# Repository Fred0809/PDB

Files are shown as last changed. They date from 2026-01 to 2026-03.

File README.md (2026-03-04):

# PDB
The project uses XT60 conenctor for battery input and screw terminals for ESCs output. The board idea is to have fuse, current measurement, and buck converter to 5V. Curent measuremnt from INA amp is sent to FCU, mounted above, with JST-XH conenctor together with 5V, VBAT voltage measurement, and GND.

<p align="center">
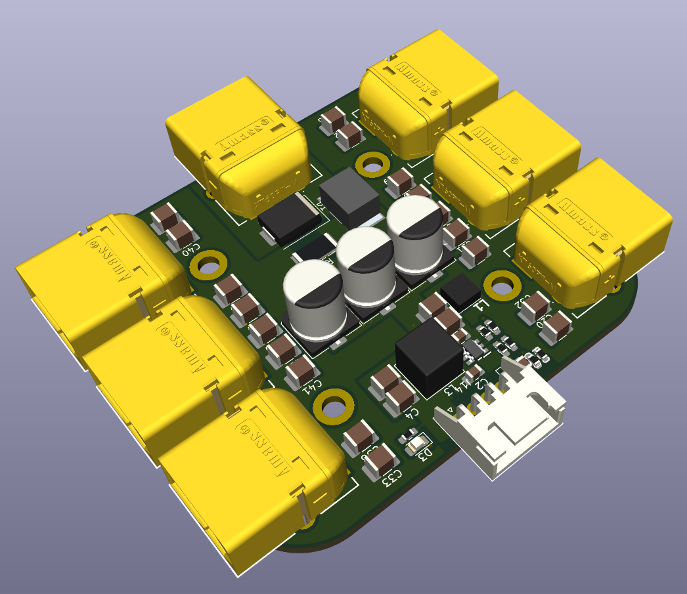
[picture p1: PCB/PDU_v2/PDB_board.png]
  
</p>

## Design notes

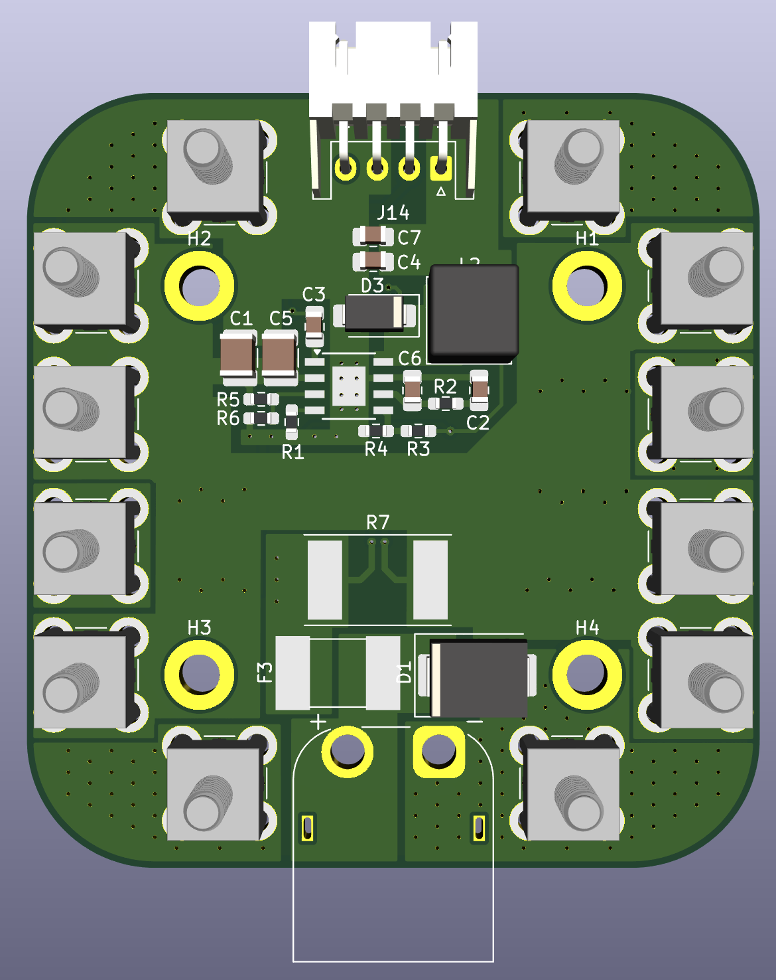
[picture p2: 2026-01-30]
PCB/PDU_v1_pcb_view.png

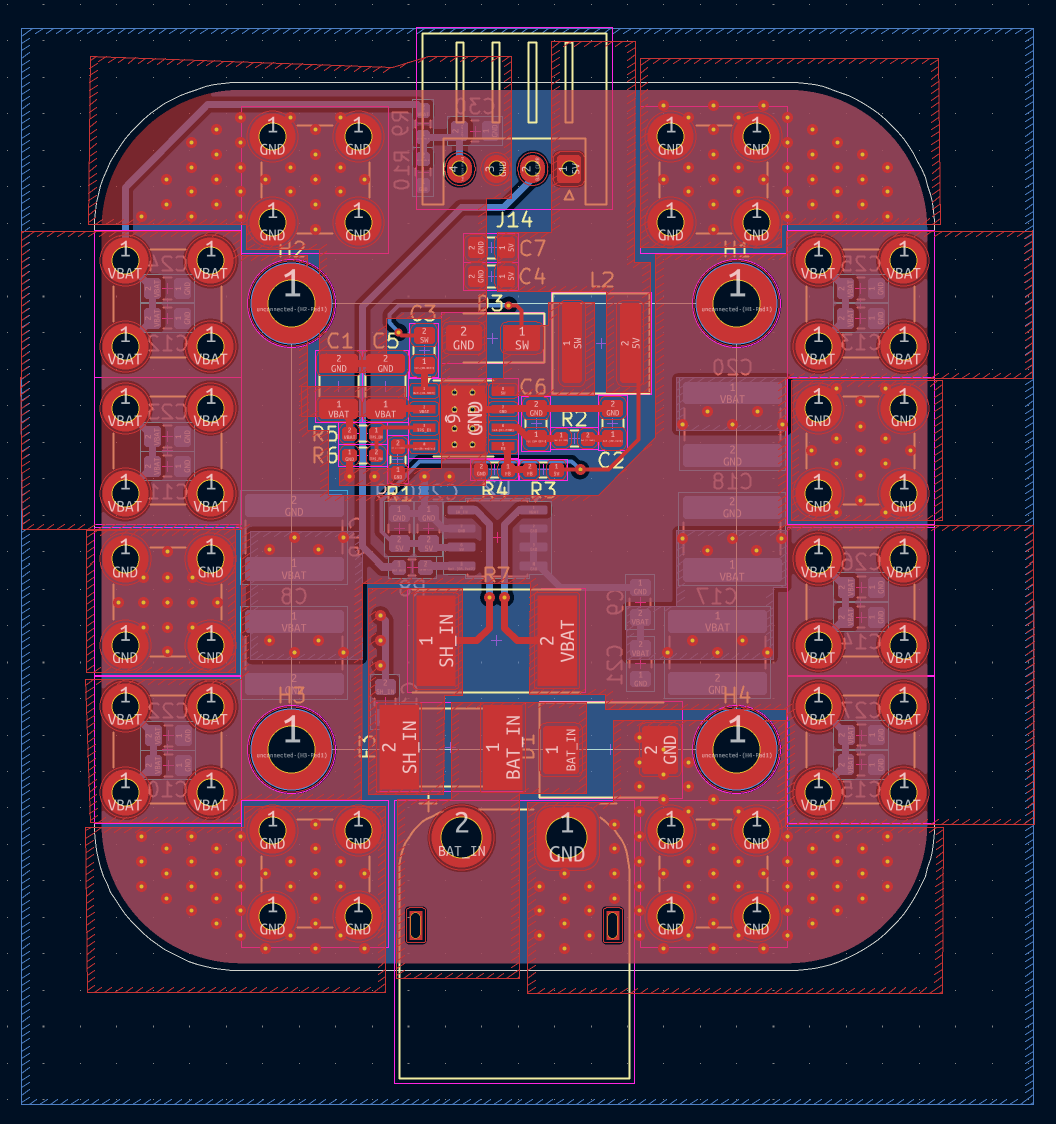
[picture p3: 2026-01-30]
PCB/PDU_v1_pcb.png

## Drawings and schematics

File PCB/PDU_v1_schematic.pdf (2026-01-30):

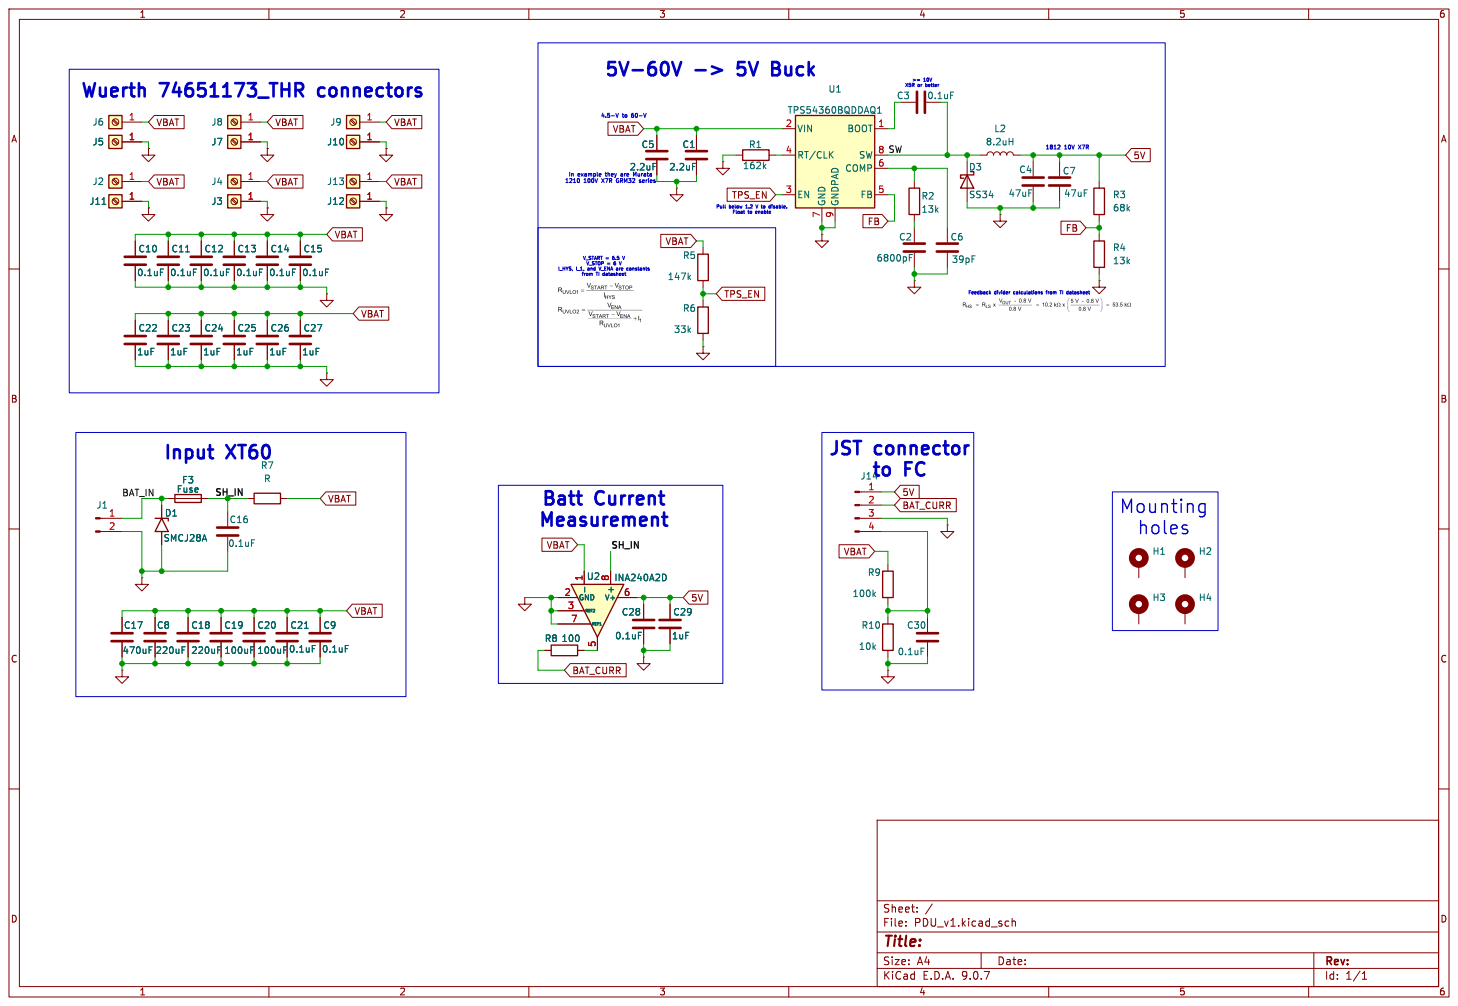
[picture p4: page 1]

9 BOOT 1 SW 8 COMP 6 FB 5 U1 TPS54360BQDDAQ1 VBAT VBAT VBAT VBAT VBAT VBAT VBAT VBAT VBAT VBAT VBAT

Id: 1/1 Title: File: PDU_v1.kicad_sch Sheet: /

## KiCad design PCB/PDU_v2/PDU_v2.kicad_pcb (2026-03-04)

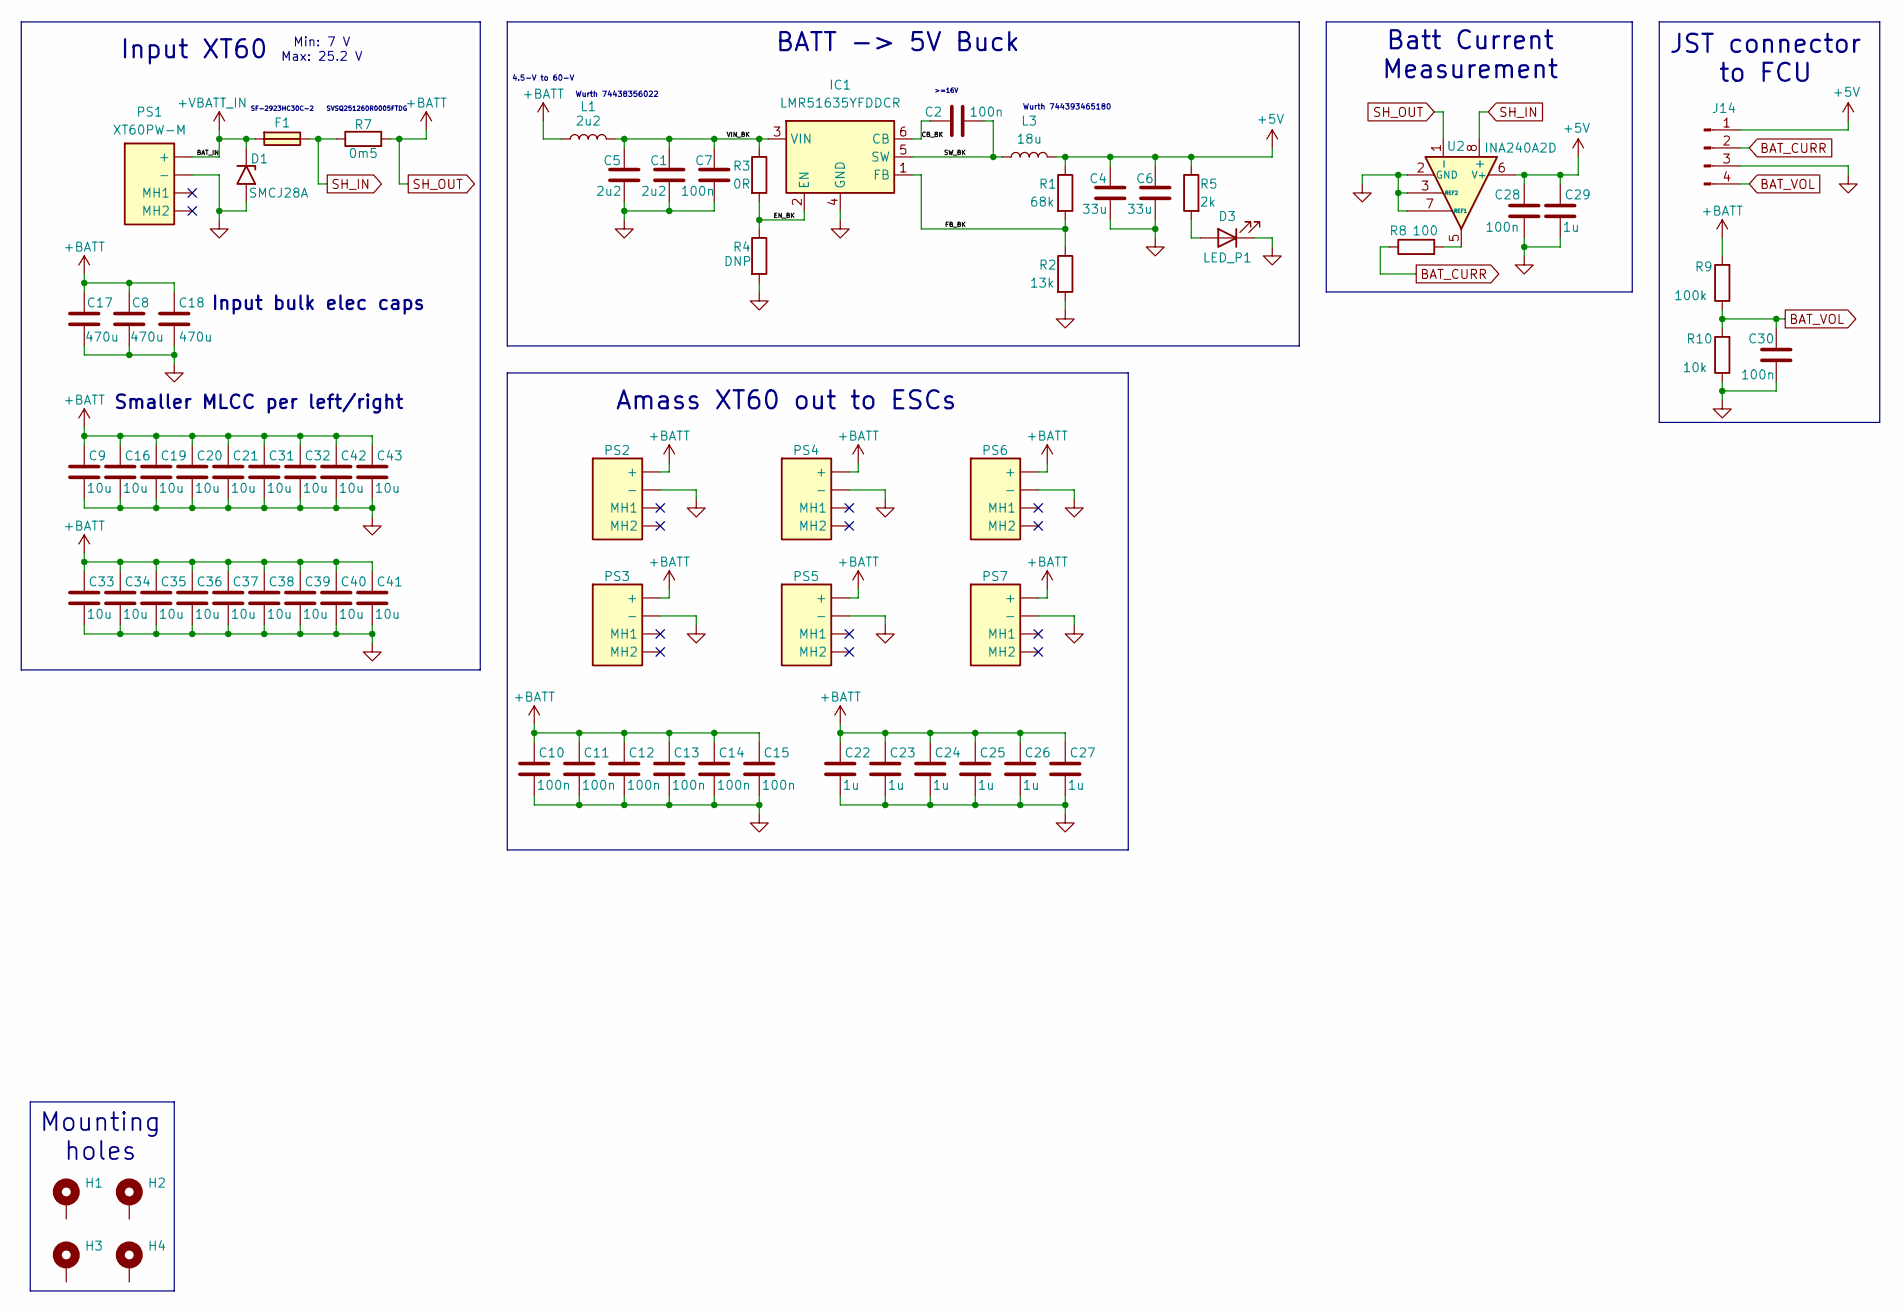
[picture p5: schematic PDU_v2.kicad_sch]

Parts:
C1, C5: 2u2; C_1210_3225Metric_Pad1.33x2.70mm_HandSolder
C2, C7, C30: 100n; C_0805_2012Metric_Pad1.18x1.45mm_HandSolder
C4, C6: 33u; C_1210_3225Metric_Pad1.33x2.70mm_HandSolder
C8, C17, C18: 470u; CP_Elec_8x10
C9, C16, C19, C20, C21, C31, C32, C33, C34, C35, C36, C37, C38, C39, C40, C41, C42, C43: 10u; C_1210_3225Metric_Pad1.33x2.70mm_HandSolder
C10, C11, C12, C13, C14, C15: 100n; C_1210_3225Metric_Pad1.33x2.70mm_HandSolder
C22, C23, C24, C25, C26, C27: 1u; C_1210_3225Metric_Pad1.33x2.70mm_HandSolder
C28: 100n; C_0603_1608Metric_Pad1.08x0.95mm_HandSolder
C29: 1u; C_0805_2012Metric_Pad1.18x1.45mm_HandSolder
D1: SMCJ28A; D_SMC
D3: LED_P1; LED_0805_2012Metric_Pad1.15x1.40mm_HandSolder
F1: SF-2923HC30C-2; SF2923HC30C2; Mouser Part Number 652-SF-2923HC30C-2
H1, H2, H3, H4: MountingHole_Pad; MountingHole_3.2mm_M3_ISO14580_Pad
IC1: LMR51635YFDDCR; SOT95P280X110-6N; Mouser Part Number 595-LMR51635YDDCR
J14: Conn_01x04_Pin; JST_XH_S4B-XH-A_1x04_P2.50mm_Horizontal
L1: 2u2; WE-MAPI_4020; Mouser Part Number 710-74438356022
L3: 18u; L_Coilcraft_XAL6060-XXX
PS1, PS2, PS3, PS4, PS5, PS6, PS7: XT60PW-M; XT60PWM; Manufacturer_Part_Number XT60PW-M
R1: 68k; R_0603_1608Metric_Pad0.98x0.95mm_HandSolder
R2: 13k; R_0603_1608Metric_Pad0.98x0.95mm_HandSolder
R3: 0R; R_0603_1608Metric_Pad0.98x0.95mm_HandSolder
R4: DNP; R_0603_1608Metric_Pad0.98x0.95mm_HandSolder
R5: 2k; R_0603_1608Metric_Pad0.98x0.95mm_HandSolder
R7: 0m5; R_2512_6332Metric_Pad1.40x3.35mm_HandSolder
R8: 100; R_0603_1608Metric_Pad0.98x0.95mm_HandSolder
R9: 100k; R_0603_1608Metric_Pad0.98x0.95mm_HandSolder
R10: 10k; R_0603_1608Metric_Pad0.98x0.95mm_HandSolder
U2: INA240A2D; SOIC-8_3.9x4.9mm_P1.27mm

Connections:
+5V: C4.1, C6.1, C28.2, C29.2, J14.1, L3.2, R1.1, R5.1, U2.6 (V+)
+VBATT_IN: D1.1 (A1), F1.1, PS1.1 (+); also elsewhere on the board
/CB_BK: C2.1, IC1.6 (CB)
/EN_BK: IC1.2 (EN), R3.2, R4.1
/FB_BK: IC1.1 (FB), R1.2, R2.1
/SW_BK: C2.2, IC1.5 (SW), L3.1
/VIN_BK: C1.1, C5.1, C7.1, IC1.3 (VIN), L1.2, R3.1
BAT_CURR: J14.2, R8.1
BAT_VOL: C30.2, J14.4, R9.1, R10.2
GND: C1.2, C4.2, C5.2, C6.2, C7.2, C8.2, C9.1, C10.1, C11.1, C12.1, C13.1, C14.1, C15.1, C16.1, C17.2, C18.2, C19.1, C20.1, C21.1, C22.1, C23.1, C24.1, C25.1, C26.1, C27.1, C28.1, C29.1, C30.1, C31.1, C32.1, C33.1, C34.1, C35.1, C36.1, C37.1, C38.1, C39.1, C40.1, C41.1, C42.1, C43.1, D1.2 (A2), D3.1 (K), IC1.4 (GND), J14.3, PS1.2 (-), PS2.2 (-), PS3.2 (-), PS4.2 (-), PS5.2 (-), PS6.2 (-), PS7.2 (-), R2.2, R4.2, R10.1, U2.2 (GND), U2.3 (REF2), U2.4 (GND), U2.7 (REF1); also elsewhere on the board
unnamed: D3.2 (A), R5.2
unnamed: R8.2, U2.5
SH_IN: F1.2, R7.1, U2.8 (+)
SH_OUT: C8.1, C9.2, C10.2, C11.2, C12.2, C13.2, C14.2, C15.2, C16.2, C17.1, C18.1, C19.2, C20.2, C21.2, C22.2, C23.2, C24.2, C25.2, C26.2, C27.2, C31.2, C32.2, C33.2, C34.2, C35.2, C36.2, C37.2, C38.2, C39.2, C40.2, C41.2, C42.2, C43.2, L1.1, PS2.1 (+), PS3.1 (+), PS4.1 (+), PS5.1 (+), PS6.1 (+), PS7.1 (+), R7.2, R9.2, U2.1 (-)

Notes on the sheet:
Mounting holes
4.5-V to 60-V
BATT -> 5V Buck
Input bulk elec caps
SF-2923HC30C-2
Input XT60
Min: 7 V Max: 25.2 V
>=16V
JST connector to FCU
Amass XT60 out to ESCs
Wurth 744393465180
Batt Current Measurement
SVSQ251260R0005FTDG
Wurth 74438356022
Smaller MLCC per left/right

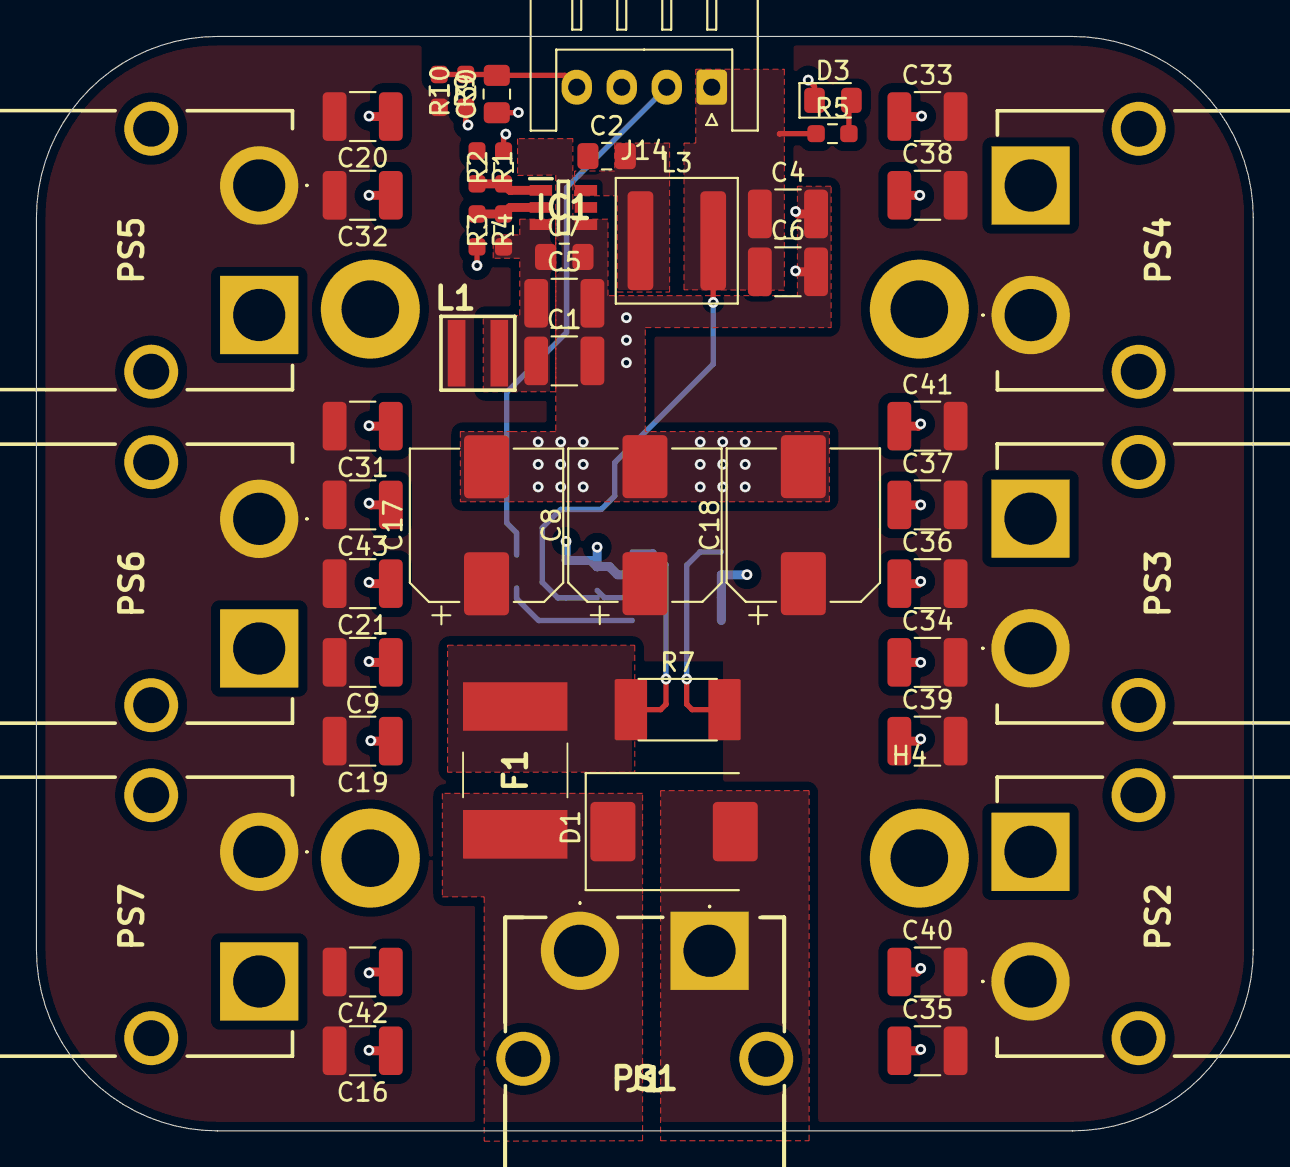
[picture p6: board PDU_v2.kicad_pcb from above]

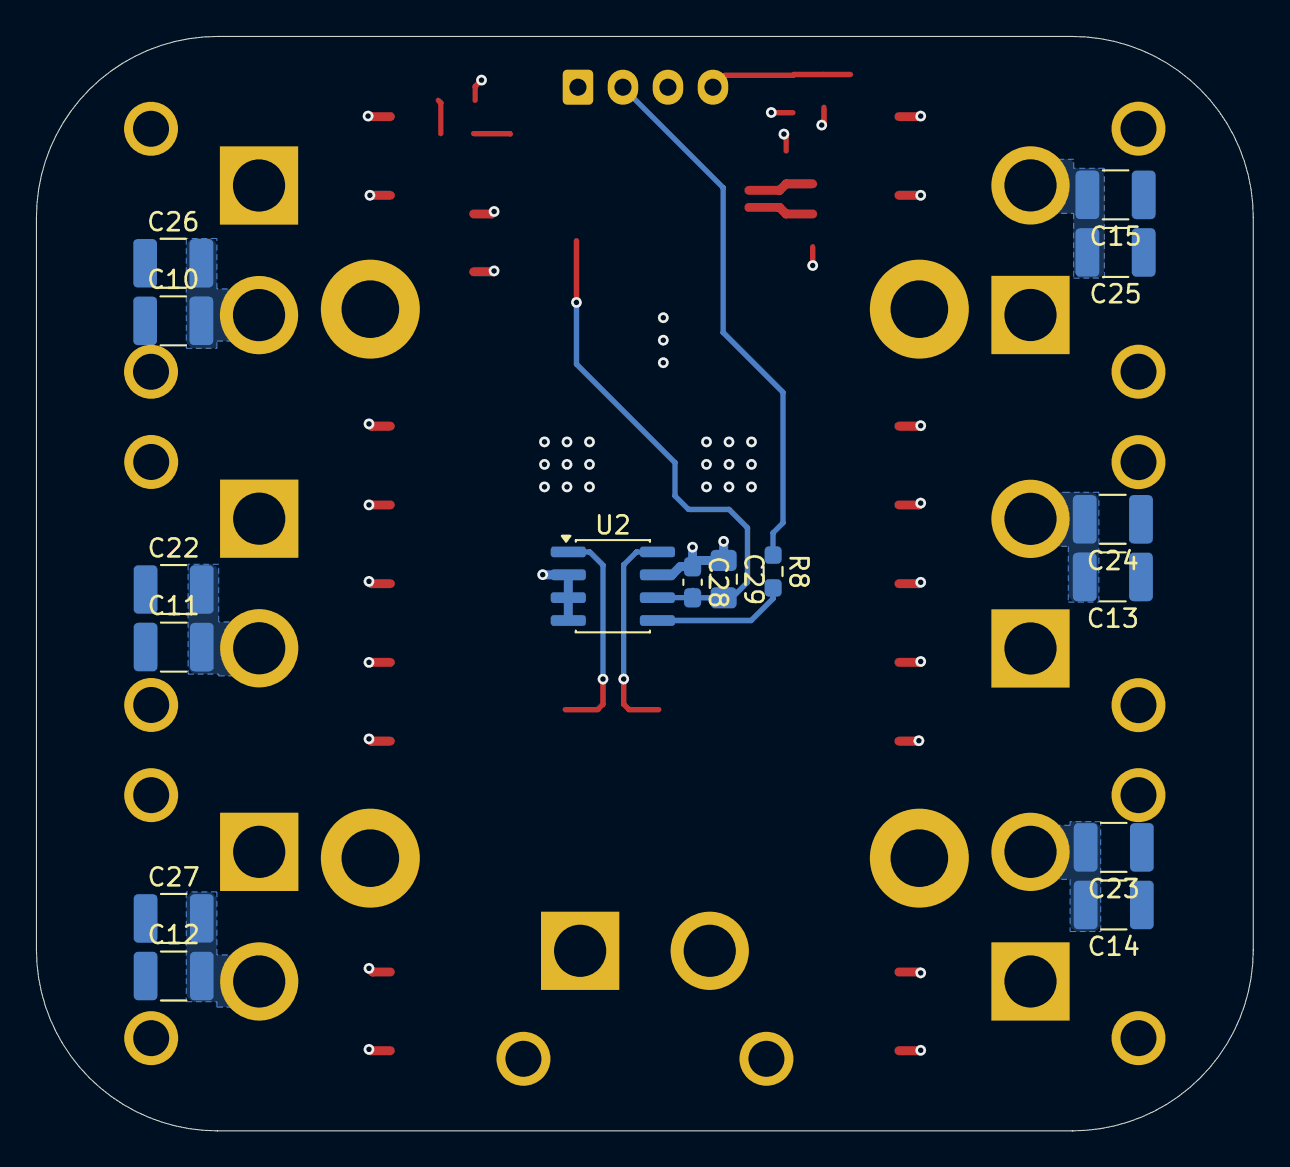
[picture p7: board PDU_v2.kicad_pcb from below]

Board: 4 copper layers, 67.6 x 60.8 mm, 71 parts (16 on the bottom side), 14 nets.

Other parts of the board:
J1: XT60PW-M; XT60PWM

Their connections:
+VBATT_IN: J1.1; also elsewhere on the board
GND: J1.2; also elsewhere on the board

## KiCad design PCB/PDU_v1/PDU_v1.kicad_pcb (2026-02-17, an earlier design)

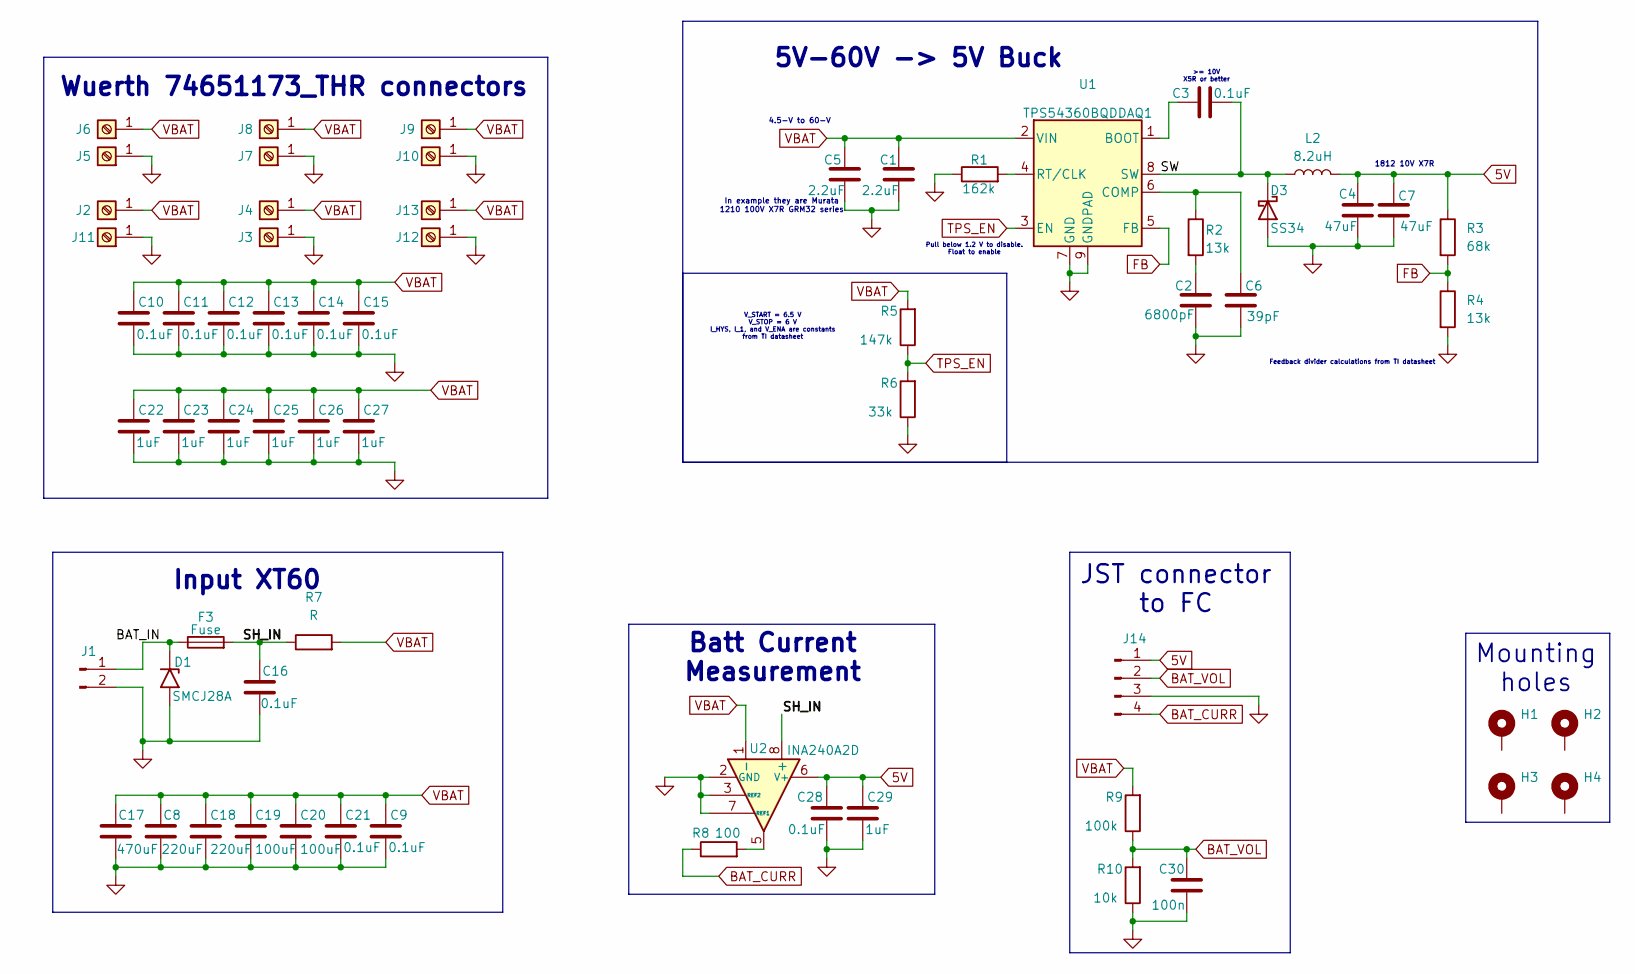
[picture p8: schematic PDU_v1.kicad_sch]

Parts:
C1, C5: 2.2uF; C_1210_3225Metric_Pad1.33x2.70mm_HandSolder
C2: 6800pF; C_0805_2012Metric_Pad1.18x1.45mm_HandSolder
C3, C9, C10, C11, C12, C13, C14, C15, C16, C21, C28: 0.1uF; C_0805_2012Metric_Pad1.18x1.45mm_HandSolder
C4, C7: 47uF; C_0805_2012Metric_Pad1.18x1.45mm_HandSolder
C6: 39pF; C_0805_2012Metric_Pad1.18x1.45mm_HandSolder
C8, C18: 220uF; C_1825_4564Metric_Pad1.57x6.80mm_HandSolder
C17: 470uF; C_1825_4564Metric_Pad1.57x6.80mm_HandSolder
C19, C20: 100uF; C_1825_4564Metric_Pad1.57x6.80mm_HandSolder
C22, C23, C24, C25, C26, C27, C29: 1uF; C_0805_2012Metric_Pad1.18x1.45mm_HandSolder
C30: 100n; C_0805_2012Metric_Pad1.18x1.45mm_HandSolder
D1: SMCJ28A; D_SMC
D3: SS34; D_SMA
F3: Fuse; Fuse_2920_7451Metric_Pad2.10x5.45mm_HandSolder
H1, H2, H3, H4: MountingHole_Pad; MountingHole_3.2mm_M3_ISO14580_Pad
J1: Conn_01x02_Pin; AMASS_XT60PW-M_1x02_P7.20mm_Horizontal
J2, J3, J4, J5, J6, J7, J8, J9, J10, J11, J12, J13: Screw_Terminal_01x01; Wuerth_REDCUBE-THR_WP-THRSH_74651173_THR
J14: Conn_01x04_Pin; JST_XH_S4B-XH-A_1x04_P2.50mm_Horizontal
L2: 8.2uH; L_Coilcraft_XAL6060-XXX
R1: 162k; R_0603_1608Metric_Pad0.98x0.95mm_HandSolder
R2, R4: 13k; R_0603_1608Metric_Pad0.98x0.95mm_HandSolder
R3: 68k; R_0603_1608Metric_Pad0.98x0.95mm_HandSolder
R5: 147k; R_0603_1608Metric_Pad0.98x0.95mm_HandSolder
R6: 33k; R_0603_1608Metric_Pad0.98x0.95mm_HandSolder
R7: R; R_Shunt_Vishay_WSR2_WSR3
R8: 100; R_0603_1608Metric_Pad0.98x0.95mm_HandSolder
R9: 100k; R_0603_1608Metric_Pad0.98x0.95mm_HandSolder
R10: 10k; R_0603_1608Metric_Pad0.98x0.95mm_HandSolder
U1: TPS54360BQDDAQ1; TI_SO-PowerPAD-8_ThermalVias
U2: INA240A2D; SOIC-8_3.9x4.9mm_P1.27mm

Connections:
5V: C4.1, C7.1, C28.2, C29.2, J14.1, L2.2, R3.1, U2.6 (V+)
/BAT_IN: D1.1 (A1), F3.1, J1.1
/SH_IN: C16.2, F3.2, R7.1, U2.8 (+)
/SW: C3.2, D3.1 (K), L2.1, U1.8 (SW)
BAT_CURR: J14.4, R8.1
BAT_VOL: C30.2, J14.2, R9.1, R10.2
FB: R3.2, R4.1, U1.5 (FB)
GND: C1.2, C2.2, C4.2, C5.2, C6.2, C7.2, C8.2, C9.1, C10.1, C11.1, C12.1, C13.1, C14.1, C15.1, C16.1, C17.2, C18.2, C19.2, C20.2, C21.1, C22.1, C23.1, C24.1, C25.1, C26.1, C27.1, C28.1, C29.1, C30.1, D1.2 (A2), D3.2 (A), J1.2, J3.1, J5.1, J7.1, J10.1, J11.1, J12.1, J14.3, R1.1, R4.2, R6.1, R10.1, U1.7 (GND), U1.9 (GNDPAD), U2.2 (GND), U2.3 (REF2), U2.4 (GND), U2.7 (REF1)
unnamed: C2.1, R2.2
unnamed: R8.2, U2.5
unnamed: C3.1, U1.1 (BOOT)
unnamed: C6.1, R2.1, U1.6 (COMP)
unnamed: R1.2, U1.4 (RT/CLK)
TPS_EN: R5.1, R6.2, U1.3 (EN)
VBAT: C1.1, C5.1, C8.1, C9.2, C10.2, C11.2, C12.2, C13.2, C14.2, C15.2, C17.1, C18.1, C19.1, C20.1, C21.2, C22.2, C23.2, C24.2, C25.2, C26.2, C27.2, J2.1, J4.1, J6.1, J8.1, J9.1, J13.1, R5.2, R7.2, R9.2, U1.2 (VIN), U2.1 (-)

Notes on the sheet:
V_START = 6.5 V V_STOP = 6 V I_HYS, I_1, and V_ENA are constants from TI datasheet
Mounting holes
4.5-V to 60-V
Pull below 1.2 V to disable. Float to enable
5V-60V -> 5V Buck
1812 10V X7R
Input XT60
Feedback divider calculations from TI datasheet
JST connector to FC
Wuerth 74651173_THR connectors
>= 10V X5R or better
In example they are Murata 1210 100V X7R GRM32 series
Batt Current Measurement

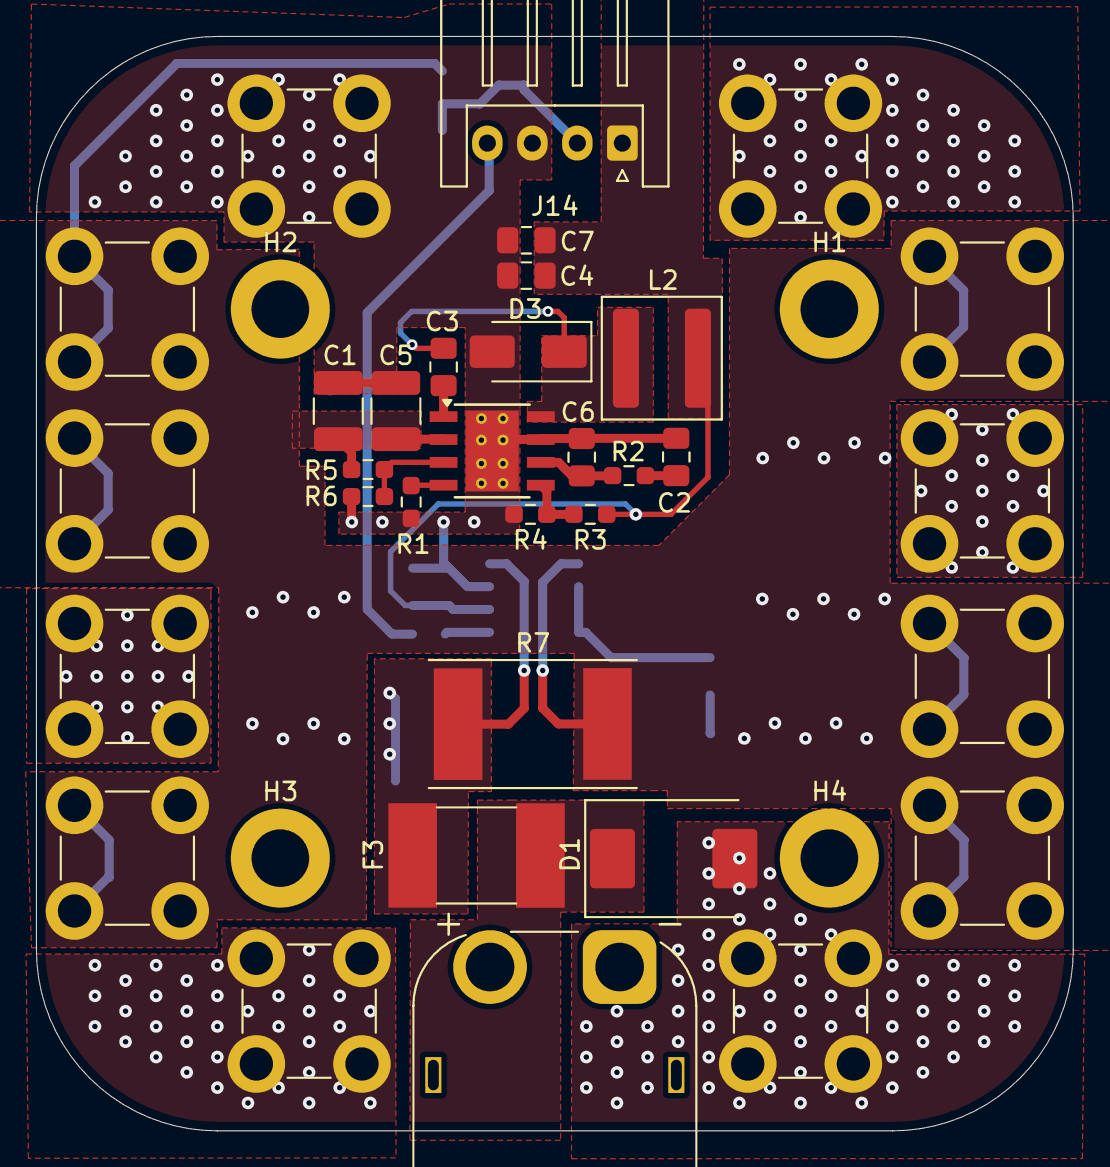
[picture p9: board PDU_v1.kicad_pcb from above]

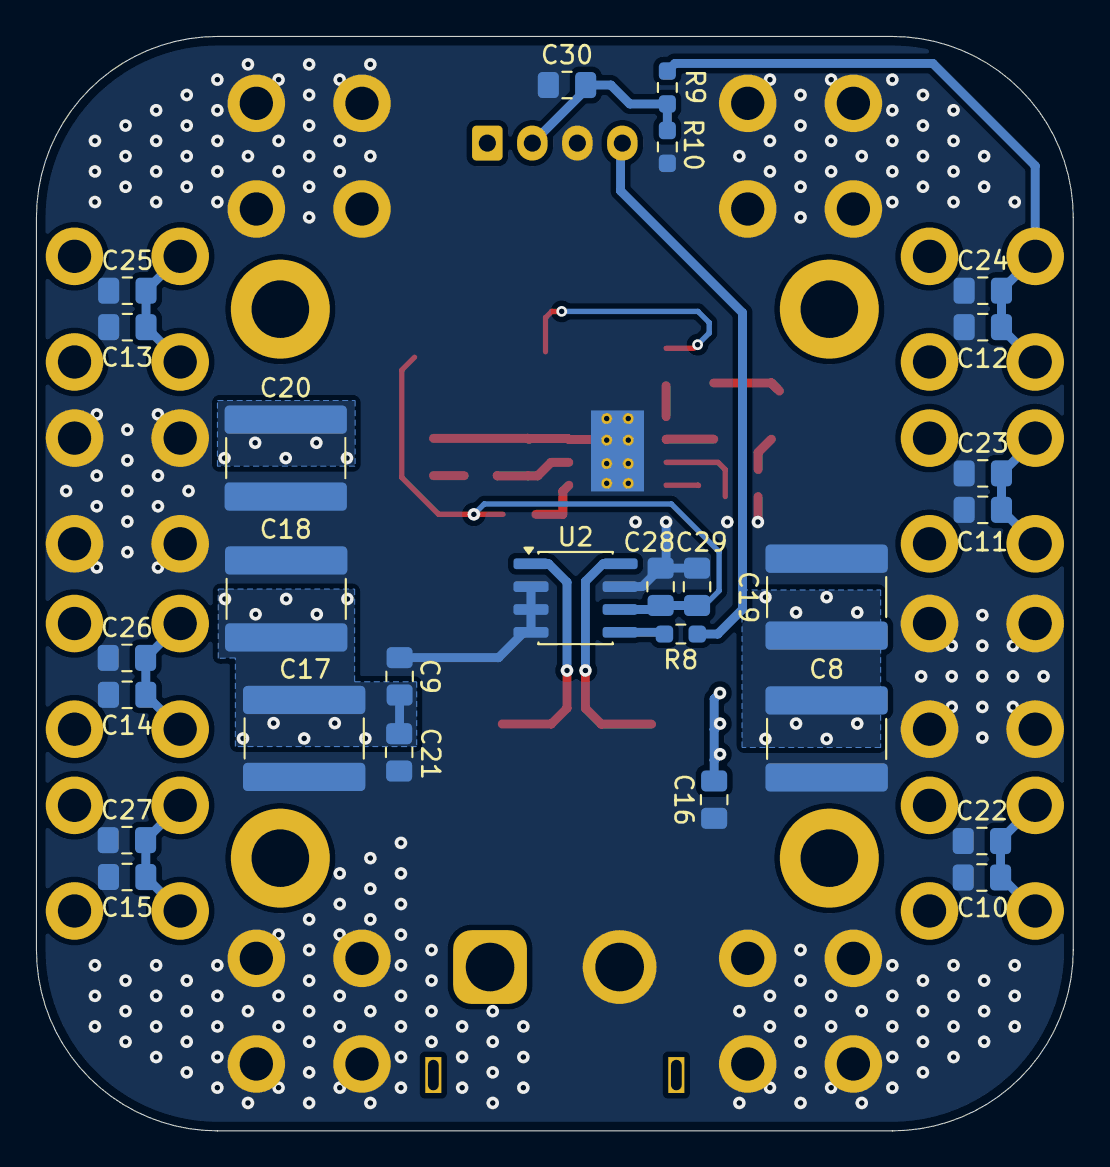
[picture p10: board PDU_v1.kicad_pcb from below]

Board: 2 copper layers, 57.6 x 60.8 mm, 64 parts (27 on the bottom side), 15 nets.

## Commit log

2026-01-30 Add PDU_v1 PCB design files and backups
    Initial commit of the PDU_v1 KiCad project, including schematic, PCB layout, project files, backup archives, and output images (PCB and schematic PDF).
    [PDU_v1.kicad_pcb, PDU_v1.kicad_sch]
2026-01-30 Enhance README with project details
    Added details about the XT60 connector, screw terminals, and current measurement.
2026-02-01 changed wording in README about current measurement
2026-02-06 Update PCB nets, footprint positions and routes
    Rename and reassign nets for clarity (e.g. Net-(J14-Pin_4) -> BAT_VOL, adjust BAT_CURR and /BAT_IN/GND assignments), adjust component placement (C30 moved and value normalized from "0.1uF" to "100n")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
    [PDU_v1.kicad_pcb, PDU_v1.kicad_sch]
2026-02-17 Created next version
    [PDU_v1.kicad_pcb, PDU_v2.kicad_pcb, PDU_v2.kicad_sch]
2026-02-17 Started working on v2
    [PDU_v2.kicad_pcb, PDU_v2.kicad_sch]
2026-02-18 Finished layout
    [PDU_v2.kicad_pcb, PDU_v2.kicad_sch]
2026-02-20 Repaired library
    [PDU_v2.kicad_pcb, PDU_v2.kicad_sch]
2026-03-04 layout update
    [PDU_v2.kicad_pcb]
